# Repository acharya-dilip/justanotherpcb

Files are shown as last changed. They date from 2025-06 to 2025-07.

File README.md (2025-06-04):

# Justanotherpcb
This is a PCB that holds chaos press the button to get a glimpse of what it holds and beware it may jump or rant at you

# Materials List:
LED's x6
Resistor (220) x6
Resistor (4.7k) x4
Resistor (47k) x2
Transistor (NPN) x2
Capacitor (10uf) x2
Push Switch x1
Mini Motor Disc x1
Buzzer x1
CR2032 Battery Cell x2

# What Does It DO?
This small fella is powered by two batteries and holds 6 LED's a mini motor disc and a buzzer. With the help of an astable multivibrator constatly switches between two states when power is provided and while the switcherooo occurs LED's in groups of 3 flash on and off while the motor and the buzzer also turn on in small bursts in sync with the groups of LED's.

# Some Glimpses








# Made By DILIP ACHARYA
Slack ID: acharyamission6
Made in a ADHD Hyperfocus state.
He'll spend the next month in recovery mode
Peace!

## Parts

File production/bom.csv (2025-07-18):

Designator | Footprint | Quantity | Value | LCSC Part #
BT1, BT2 | BatteryHolder_Keystone_3034_1x20mm | 2 | Battery_Cell
BZ1 | MagneticBuzzer_ProSignal_ABI-009-RC | 1 | Buzzer
C1, C2 | CP_Radial_D8.0mm_P5.00mm | 2 | C
D1, D2, D3, D4, D5, D6 | LED_D5.0mm | 6 | LED
M1 | PinHeader_1x02_P2.54mm_Vertical | 1 | Motor_DC
Q1, Q2 | TO-92L_HandSolder | 2 | NPN
RLA1, RLA2 | R_Axial_DIN0207_L6.3mm_D2.5mm_P7.62mm_Horizontal | 2 | R_Large_AMV
RSA1, RSA2 | R_Axial_DIN0207_L6.3mm_D2.5mm_P7.62mm_Horizontal | 2 | R_Small_amv
RSB1 | R_Axial_DIN0207_L6.3mm_D2.5mm_P7.62mm_Horizontal | 1 | R_Small_buzzer
RSD1, RSD2, RSD3, RSD4, RSD5, RSD6 | R_Axial_DIN0207_L6.3mm_D2.5mm_P7.62mm_Horizontal | 6 | R_Small_LED
RSM1 | R_Axial_DIN0207_L6.3mm_D2.5mm_P7.62mm_Horizontal | 1 | R_Small_motor
SW1 | SW_PUSH_6mm | 1 | SW_Push

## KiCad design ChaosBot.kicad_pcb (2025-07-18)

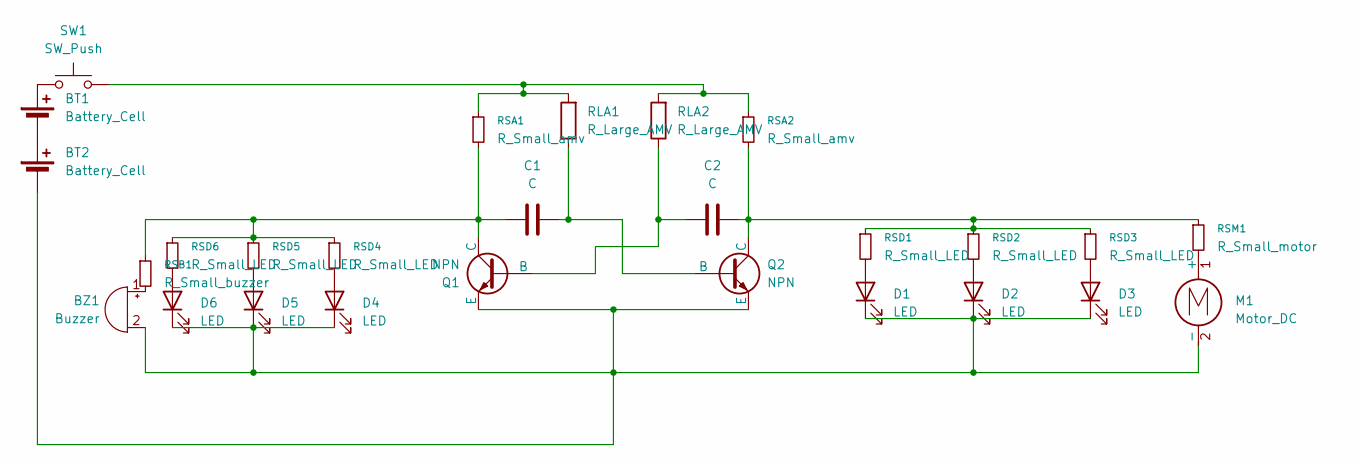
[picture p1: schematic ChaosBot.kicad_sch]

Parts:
BT1, BT2: Battery_Cell; BatteryHolder_Keystone_3034_1x20mm
BZ1: Buzzer; MagneticBuzzer_ProSignal_ABI-009-RC
C1, C2: C; CP_Radial_D8.0mm_P5.00mm
D1, D2, D3, D4, D5, D6: LED; LED_D5.0mm
M1: Motor_DC; PinHeader_1x02_P2.54mm_Vertical
Q1, Q2: NPN; TO-92L_HandSolder
RLA1, RLA2: R_Large_AMV; R_Axial_DIN0207_L6.3mm_D2.5mm_P7.62mm_Horizontal
RSA1, RSA2: R_Small_amv; R_Axial_DIN0207_L6.3mm_D2.5mm_P7.62mm_Horizontal
RSB1: R_Small_buzzer; R_Axial_DIN0207_L6.3mm_D2.5mm_P7.62mm_Horizontal
RSD1, RSD2, RSD3, RSD4, RSD5, RSD6: R_Small_LED; R_Axial_DIN0207_L6.3mm_D2.5mm_P7.62mm_Horizontal
RSM1: R_Small_motor; R_Axial_DIN0207_L6.3mm_D2.5mm_P7.62mm_Horizontal
SW1: SW_Push; SW_PUSH_6mm

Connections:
unnamed: BT1.1 (+), SW1.1
unnamed: BT1.2 (-), BT2.1 (+)
unnamed: BT2.2 (-), BZ1.2 (-), D1.1 (K), D2.1 (K), D3.1 (K), D4.1 (K), D5.1 (K), D6.1 (K), M1.2 (-), Q1.3 (E), Q2.3 (E)
unnamed: BZ1.1 (+), RSB1.2
unnamed: D1.2 (A), RSD1.2
unnamed: D2.2 (A), RSD2.2
unnamed: D3.2 (A), RSD3.2
unnamed: D4.2 (A), RSD4.2
unnamed: D5.2 (A), RSD5.2
unnamed: D6.2 (A), RSD6.2
unnamed: M1.1 (+), RSM1.2
unnamed: C2.1, Q1.2 (B), RLA2.1
unnamed: C1.1, Q1.1 (C), RSA1.2, RSB1.1, RSD4.1, RSD5.1, RSD6.1
unnamed: C1.2, Q2.2 (B), RLA1.1
unnamed: C2.2, Q2.1 (C), RSA2.2, RSD1.1, RSD2.1, RSD3.1, RSM1.1
unnamed: RLA1.2, RLA2.2, RSA1.1, RSA2.1, SW1.2

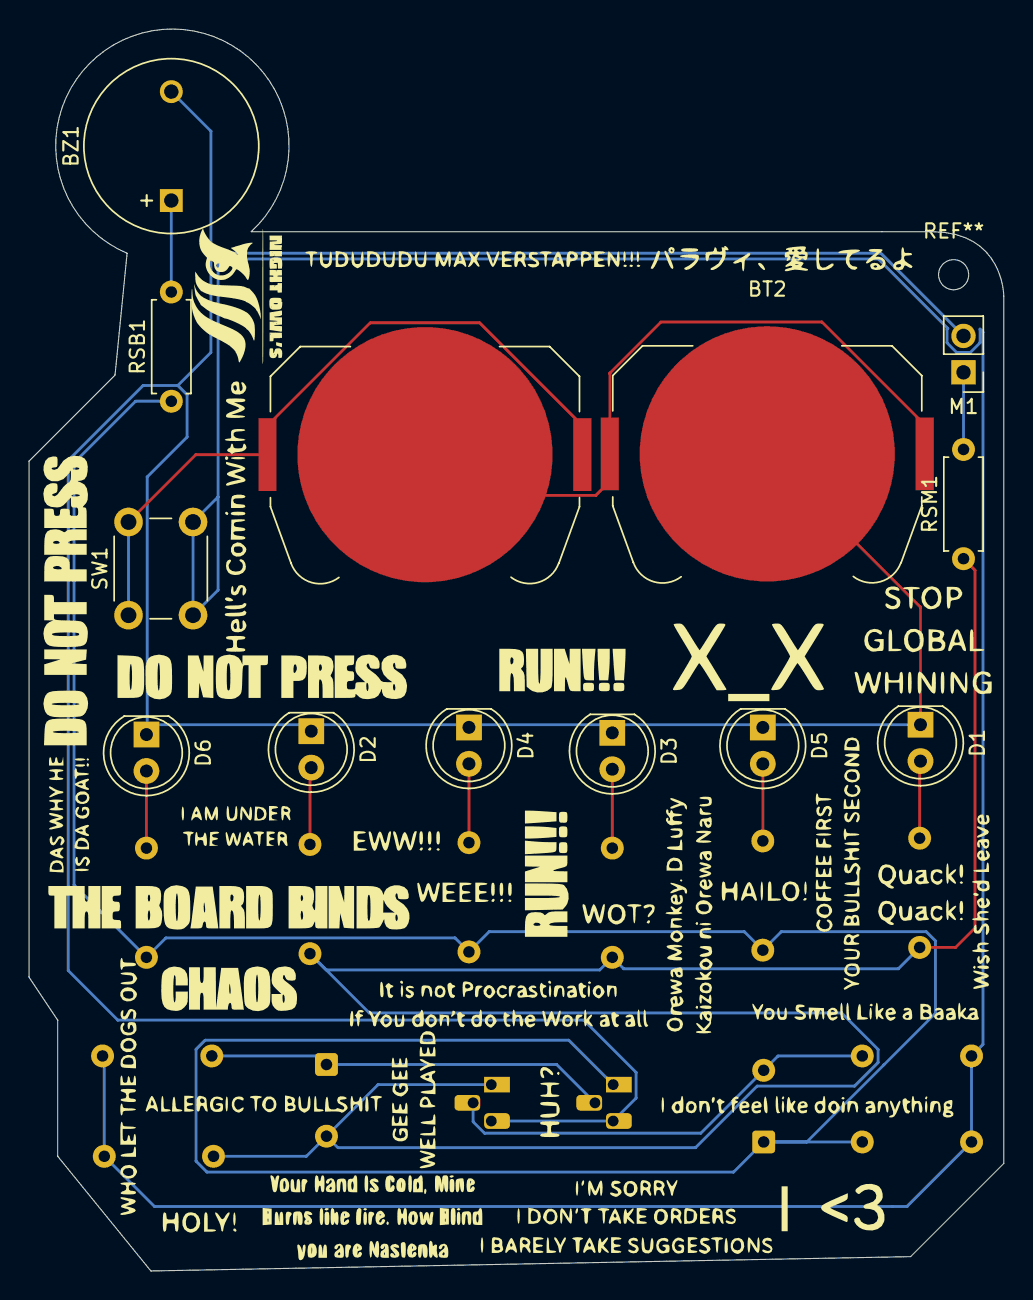
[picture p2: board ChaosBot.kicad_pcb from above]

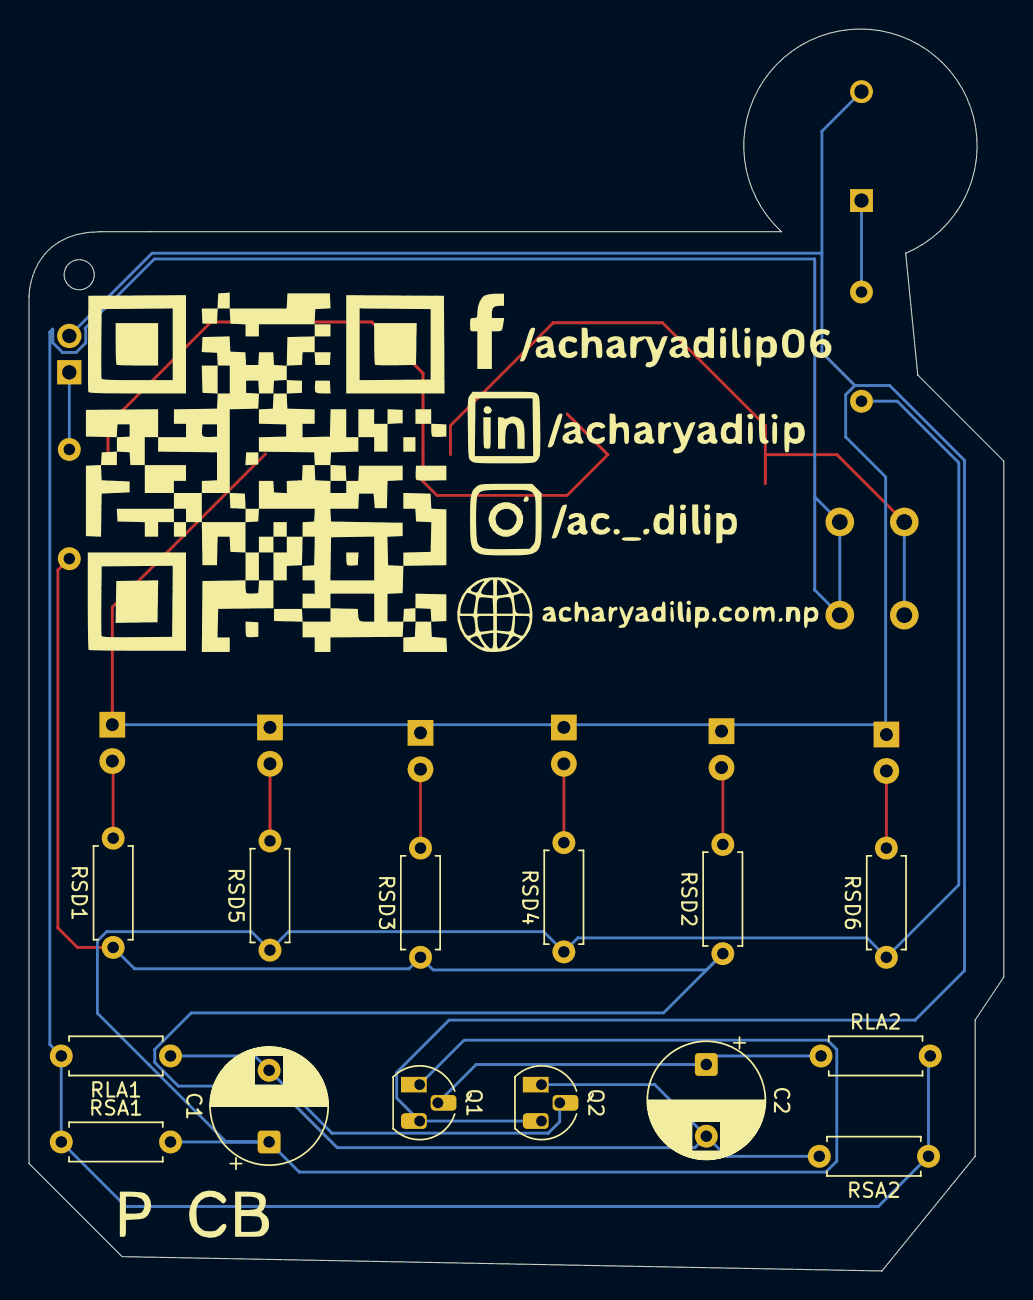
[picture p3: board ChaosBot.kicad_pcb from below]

Board: 2 copper layers, 68.0 x 86.6 mm, 27 parts (14 on the bottom side), 16 nets.

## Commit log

2025-06-03 Updated Readme.md with the PCB description
2025-06-03 Uploaded the Schematics and PCB design for the PCB
    [Chaos Circuit.kicad_pcb, Chaos Circuit.kicad_sch]
2025-06-03 Uploaded the correct files
    [ChaosBot.kicad_pcb, ChaosBot.kicad_pcb_bom.csv, ChaosBot.kicad_pcb_positions.csv]
2025-06-03 Update README.md with the photos of the circuit
2025-06-04 Delete pcbway_production/2025-06-03-07-09-20 directory as it was outdated
    the battery holders were oriented the wrong way in the PCB
    [ChaosBot.kicad_pcb_bom.csv, ChaosBot.kicad_pcb_positions.csv]
2025-06-04 Rotated the battery holder by 90 degree
    As it was not possbile to insert the batteries in the previous instance of the PCB
    [ChaosBot.kicad_pcb, ChaosBot.kicad_pcb_bom.csv, ChaosBot.kicad_pcb_positions.csv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]
2025-06-04 Update README.md
    Corrected the image of the PCB after rotating the battery holders in the desgin by 90 degrees
2025-06-04 Rotated the battery by 180 degree
    [ChaosBot.kicad_pcb]
2025-06-04 correct gerber files for the rotated PCB
    [ChaosBot.kicad_pcb_bom.csv, ChaosBot.kicad_pcb_positions.csv]
2025-07-18 Added the Links in SS
    [ChaosBot.kicad_pcb]
2025-07-18 Updated the production files
    [ChaosBot.kicad_pcb_bom.csv, ChaosBot.kicad_pcb_positions.csv, bom.csv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]
